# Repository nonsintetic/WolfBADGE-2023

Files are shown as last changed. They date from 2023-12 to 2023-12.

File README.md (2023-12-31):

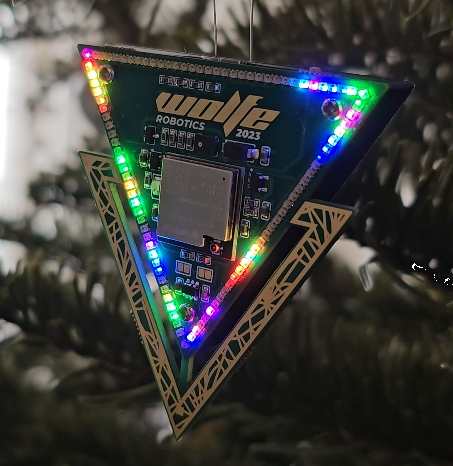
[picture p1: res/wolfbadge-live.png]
WolfBADGE-2023


# WolfBADGE-2023
 This is the Official Wolf-e Robotics end of year badge. Every year we create something to celebrate the end of the year. This year it's an ornament / fridge magnet / desktop toy thing with a ton of addressable LEDs and WiFi connectivity. Feel free to remix it into your own fun design and poke us on social media if you do, we'd love to see it.

# Hardware
 We used an ESP32 microcontroller module as the main processor. 
 
 The touch IC is connected to GPIO36 and will output HIGH when the decorative triangle pad is touched. There are two solder bridges you can link to configure the button to be a toggle switch and change it from active HIGH to active LOW.

 There is a PDM microphone on board connected to the ESP32 GPIO that can be configured in WLED. PDM DATA is on GPIO32 and PDM CLK is on GPIO15.

 The board as a battery charger build-in, just plug in USB and the battery will be charged. Default current is 200mA, change R3 to adjust the charge current.

# Firmware
 We used the MoonModules fork of WLED to support sound reactivity. You can find our config file 

# Power consumption
 We limited the leds to 250mA in WLED (the minimum allowed setting in WLED), but these particular pixels use a lot less power. We measured around 140mA at full blast with WiFi on and connected (with the WLED limit in place). So a 250mA battery should be more than enough to give you over an hour battery life (and will generally fit on the back without issues).

# 3D printed case
 We included a 3D printed case to hide the battery on the back of the module, it's a bit of a fast and dirty design since we ran out of time.

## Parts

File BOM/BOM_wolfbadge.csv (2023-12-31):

ID | Name | Designator | Footprint | Quantity | Manufacturer Part | Manufacturer | Supplier | Supplier Part | Price
1 | ESP32-MINI-1U-N4_C2980304 | U101 | WIFIM-SMD_ESP32-MINI-1U | 1 | ESP32-MINI-1U-N4 | ESPRESSIF(乐鑫) | LCSC | C2980304 | 2.641
2 | 10uF | C4,C2,C1,C3 | C0603 | 4 | C0603X5R106K6R3NT | SANYEAR(叁叶源) | LCSC | C475250 | 0.012
3 | 5.1kΩ | R5,R6,R1,R2,R3,R7,R8,R9,R10,R11,R12,R13 | R0603 | 12 | PTFR0603D5K10P9 | RESI(开步睿思） | LCSC | C369945 | 0.049
4 | AP3415E | Q1 | SOT-23-3_L2.9-W1.4-P1.90-LS2.5-BR | 1 | AP3415E | ALLPOWER(铨力) | LCSC | C2876004 | 0.047
5 | 33pF | C5 | C0603 | 1 | CL10C330JB8NNNC | SAMSUNG(三星) | LCSC | C1663 | 0.006
6 | 100nF | C6,C30 | C0603 | 2 | CC0603KRX7R9BB104 | YAGEO(国巨) | LCSC | C14663 | 0.002
7 | SS54_C22452 | D1 | SMA_L4.4-W2.8-LS5.4-R-RD | 1 | SS54 | MDD | LCSC | C22452 | 0.038
8 | MCP73831T-2ACI/OT | U102 | SOT-23-5_L3.0-W1.7-P0.95-LS2.8-BL | 1 | MCP73831T-2ACI/OT | MICROCHIP(美国微芯) | LCSC | C424093 | 0.748
9 | AP2112K-3.3TRG1 | U103 | SOT-25-5_L2.9-W1.6-P0.95-LS2.8-BL | 1 | AP2112K-3.3TRG1 | DIODES(美台) | LCSC | C51118 | 0.093
10 | MP34DT05TR-A | U105 | MIC-SMD_5P-L3.0-W4.0-P0.85-BL | 1 | MP34DT05TR-A | ST(意法半导体) | LCSC | C2688664 | 1.198
11 | TTP233H-BA6 | U106 | SOT-23-6_L2.9-W1.7-P0.95-LS2.8-BL | 1 | TTP233H-BA6 | TONTEK(通泰) | LCSC | C2890349 | 0.137
12 | LED | U2,U3,U4,U5,U6,U7,U8,U9,U10,U11,U12,U13,U14,U15,U16,U17,U18,U19,U20,U21,U22,U23,U24,U25,U26,U27,U28,U29,U30,U31,U32,U33,U34,U35,U36,U37,U38,U39,U40,U41,U42,U43,U44,U45,U46,U47,U48,U49,U50,U51,U52,U53,U54,U55,U56,U57,U58,U59,U60,U61,U62,U63,U64,U65,U66,U67,U68,U69,U70,U71,U72,U73,U74,U75,U76,U77,U78,U79,U80,U81,U82,U83,U84,U85,U86,U87,U88,U89,U90,U91,U92,U93,U94,U95,U96,U97,U98,U99,U100 | LED-SMD_4P-L1.0-W1.0-TL_XL-1010RGBC-WS2812B | 99 | XL-1010RGBC-WS2812B | XINGLIGHT(成兴光) | LCSC | C5349953 | 0.053
13 | TA-3524A-A1-W | SW1 | SWITCH-CONN-TH_TA-3524A-A2 | 1 | TA-3524A-A1-W | Yuandi(元迪) | LCSC | C730329 | 0.08
14 | YTC-TC16-273A1 | U107 | TYPE-C-SMD_YIYUAN_YTC-TC16-273A1-NO_HOLES | 1 | YTC-TC16-273A1 | YIYUAN(怡远) | LCSC | C5260486 | 0.126
15 | BAT | J4 | HDR-M-2.54_1X2 | 1 |  |  | LCSC | C124375 | 0.022

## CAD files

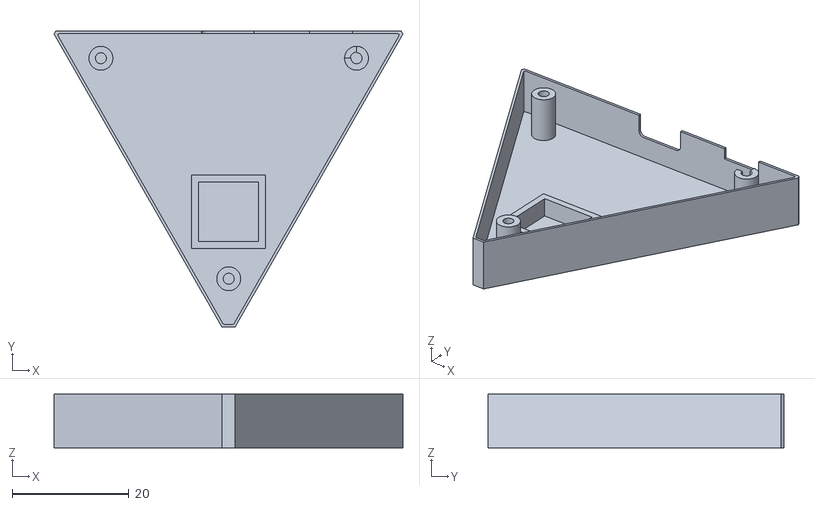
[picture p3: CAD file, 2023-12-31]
3D Printed Case/wolfbox-case.stl
59.8 x 50.7 x 9.20

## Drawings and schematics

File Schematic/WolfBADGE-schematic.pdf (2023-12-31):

USB-C Port | Battery Charger | Touch Detection
| 200mA charge current

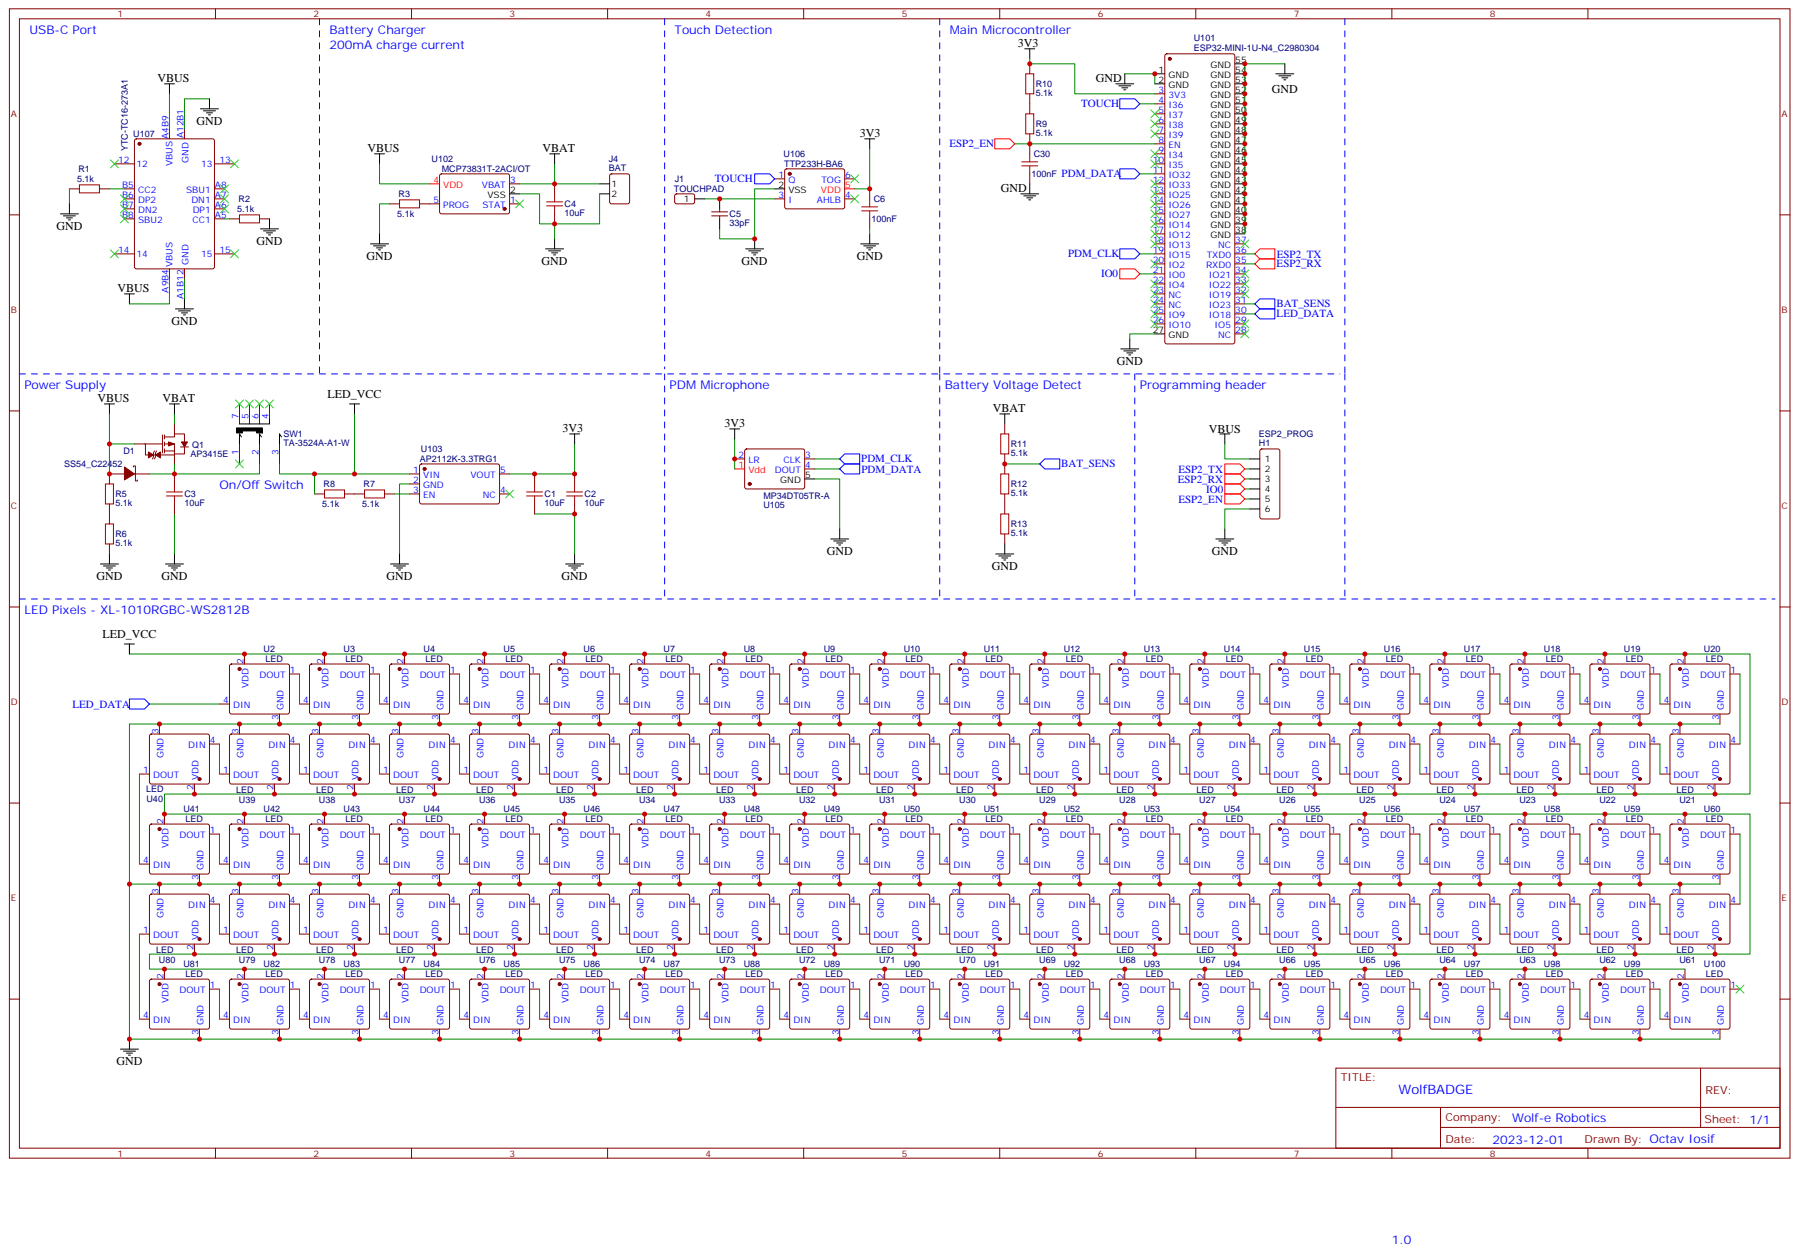
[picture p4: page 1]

Drawn By: Octav Iosif

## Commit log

2023-12-31 case, wled config, readme
    Added case 3d print files, wled config and updated the README.
    [wolfbox-case.stl]
2023-12-31 Rev2
    updated PCB files for revision 2
    added BOM and CPL files
    [BOM_wolfbadge.csv, PickAndPlace_wolfbadge.csv]
